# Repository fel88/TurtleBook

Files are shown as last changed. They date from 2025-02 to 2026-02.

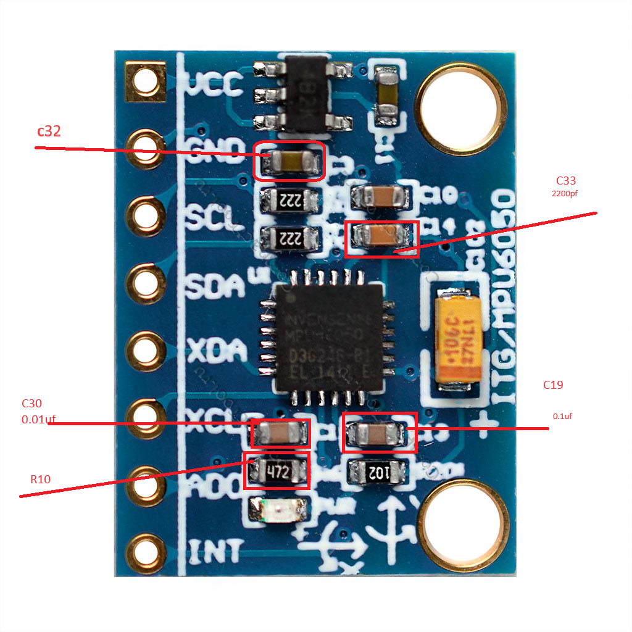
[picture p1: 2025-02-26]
pcbs/1369_1.png

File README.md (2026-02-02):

# TurtleBook

"_One book to read them all_"



Zero buttons, solar powered, fully autonomous and hermetic e-book reader.

For everyone who loves reading books and DIY projects.

Instructables:
https://www.instructables.com/Solar-Powered-Zero-Buttons-E-book-Reader/

WYSIWYG e-book. 

### Hardware
- Arduino MEGA2560 (https://aliexpress.ru/item/32967417746.html?sku_id=66568659813)
- Waveshare E-ink display 5,83” (648×480)  https://www.waveshare.com/5.83inch-e-paper.htm
- FRAM memory (FM24W256-GTR)
- WaveShare shield https://www.waveshare.com/product/displays/e-paper/e-paper-shield-b.htm
- Crystal oscillator KSE-7U16000MAB143ZA3
- OLED display (128x32 i2c)
- INA219 (https://aliexpress.ru/item/33047166203.html?sku_id=12000044300903777)
- SD-card slot
- MPU6050 (instead of buttons)
- Reed switch (turn on/off)
- Lithium-ion capacitors (LIC) 4x200F  (https://en.cda-cap.com/index.php/product/lib-series/) (https://item.szlcsc.com/3567431.html?lcsc_vid=QlRbX1wET1gIUAZeFVIKBFxWEwVWBVUAEVQKVVxUEwMxVlNSR1daUF1WT1RZXztW)
- Solar panel (something like this https://aliexpress.ru/item/1005008193807038.html?sku_id=12000044193770138)
- Buck-boost converter (https://aliexpress.ru/item/1005001525710076.html)
- NeoPixel (not necessarily)
- TL431 SOT89
- Ideal diodes (MAX40203), transistor (D882), resistors, etc
- Wires (https://aliexpress.ru/item/32793368381.html?sku_id=64310577090)

## How to assemble PCB 

### Panel driver PCB v5.0 (SRAM + Charger + Wifi integrated)
изображение

### Panel driver PCB v3.0 (no charger, no wifi)


You need next components to solder PCB board:
1. Arduino MEGA2560 
2. Waveshare shield
3. MPU6050
4. INA219
5. Crystal quartz
6. FRAM
   
## How to switch pages?

https://github.com/user-attachments/assets/5e0592eb-202e-4b6f-8b21-0b80249d7fce

## How many pages can I read?

If you have 3 LIC charged to 3.88V you can read about 880 pages (LICs will be discharged to 3.05V)

## How to convert books?
There are two options to convert (fb2/pdf/djvu/raw → cb): 
1. https://github.com/fel88/pdf2eink 
2. https://github.com/fel88/bookloader 

## Sample books
<a href="https://github.com/fel88/TurtleBook/blob/main/samples/nemo.zip">Twenty Thousand Leagues Under the Seas (Jules Verne)</a>

## Wifi (optional)

You can add Wemos D1 v3 module in order to use Wifi 

изображение

There are two ways of WiFi usage at the moment:
1. Wifi Access point: Web page (upload, download books). Use your phone/laptop to load books via browser
2. P2P sender/reciever. Direct book 2 book sharing

Components:
1. Wemos d1 v3 module
2. PNP transistor 2N3906
3. resistor 330

## Charger

A pass (series) regulator based on TL431 (adjust the output voltage level to ~3.95-3.98V)

Components:
1. resistor 330Ohm, 47kOhm
2. TL431
3. D882 (almost any NPN will do)
4. MAX40203
5. Pot 47kOhm

charger5

## Weight

Approx. 260g (with wemos d1)

## Gallery









## History

I am a big fan of reading books, so I've decided to make a small contribution to the world of e-readers .

I travel on the train a lot and I needed some reliable reader. That's why I decided to make DIY e-book reader.

Default e-readers have so many needless options. But all you need 99% of time is turn to next page.

E-ink paper don't consume power till you read it without switching. So Eink+solar power is very suitable combination of technologies.

This book doesn't contain any physical buttons. There is accelerometer inside the book and it can recognize your gestures. It can be used in discrete way (to switch page or to switch menu position in both directions), or it can be used in analog way (e.g. to set brightness of the NeoPixel led)

To turn on the book you just move special plastic key in special place. The internal reed switch will be activated and the book will turn on.

This book has some distinctions from the default e-reader and satisfy my needs better.

   - Solar powered (more autonomous)
   - No buttons. (you need to make some effort to switch the page like in real book)
   - Hybrid capacitors (LIC) instead of batteries
   - Sealed / hermetic ( you can use compound+expoxy resin to totally sealed the book and it'll become water proof)
   - More reliable plexiglass case . You can put cup of coffee on it or you can throw it in your backpack and not worry that it will break.
   - Nothing useless in the firmware
   - Open hardware and firmware
   - Eink for reading and small OLED for quick response menu operations

## Pre-history

It was inspired by my old project https://github.com/fel88/BIP and couple of github projects (https://hackaday.io/project/189366-supercaps-solar-panel-project/details) solar panel + supercap (https://github.com/aresta/Supercaps  it seems that it was moved to https://github.com/aresta/ESP32-C3_Supercaps )

Great quote from Aresta/Supercaps project:


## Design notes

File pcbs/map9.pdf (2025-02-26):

Sheet1
panel driver | | waveshare
R10 | 1K | R2
C19 | 100nF C11
C15 | 100nF C19
C1 | 100nF C8
C10 | 1uF | C6
C11 | 1uF | C7
C2 | 1uF | C9
C3 | 1uF | C10
C4 | 1uF | C12
C5 | 1uF | C13
C6 | 1uF | C14
C7 | 1uF | C15
C8 | 1uF | C16
C13 | 100nF C1
C18 | 100nF C2
D4 | | D1
R9 | 1K | R1
U3 | | U2
C17 | | C3
C16 | | C5
R8 | | R7
C14 | | C4
Q2 | | Q2
R6 | | R6
Q3 | | Q3
R4 | | R8
R3 | | R9
R5 | | R11
R7 | | R10
Q1 | | Q1
D3 | | D4
L1 | | L1

Sheet1
C9 | 4.7uF C18
C12 | 100nF C17
D2 | | D3
D1 | | D2
R2 | | R3
R1 | 10K | R5
panel driver | | mega
R11 | | R10
R12 | | R11
R13 | | R12
R14 | | R13
LED1 | | LED1
LED2 | | LED2
LED3 | | LED3
LED4 | | LED4
R15 | | R2
R16 | | R4
R17 | | R14
D5 | | D2
C21 | | C12
C25 | 0.1uF C1
C20 | 22uF | C11
C24 | 0.1uF C6
C26 | 0.1uF C7
C27 | 0.1uF C8
C28 | 0.1uF C9
C29 | 0.1uF C10
U4 | | U4
Y1 | 16Mhz Y2
C22 | 12pF | C13
C23 | 12pF | C14
R18 | 1M | R15

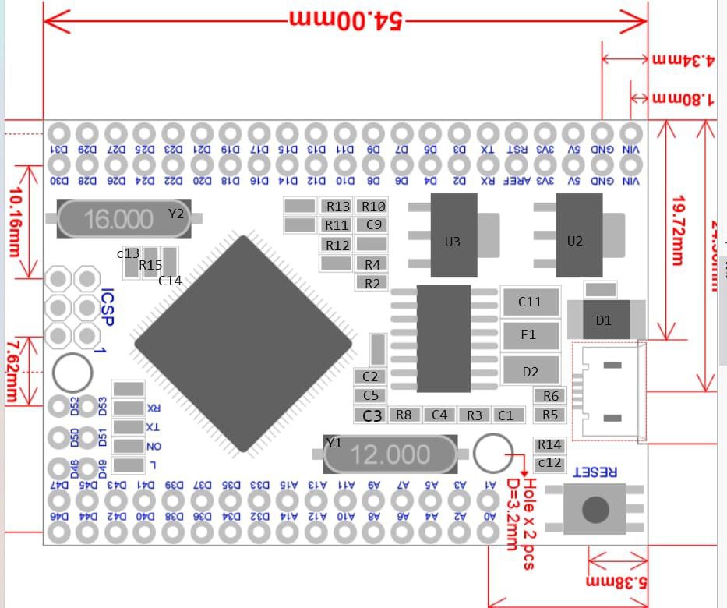
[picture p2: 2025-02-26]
pcbs/mega.jpg

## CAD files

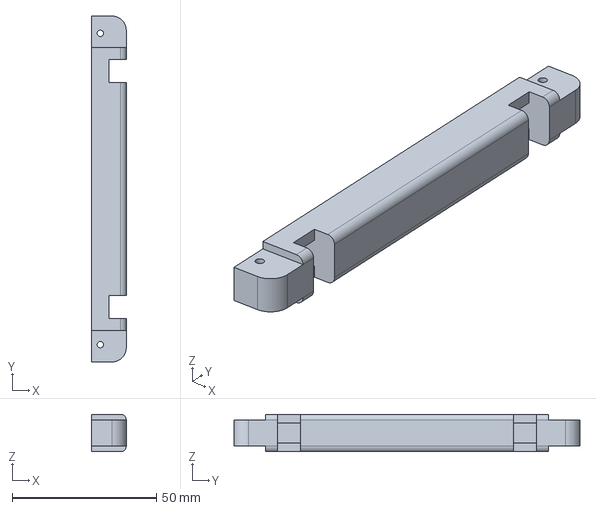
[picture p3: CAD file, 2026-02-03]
case/sider_stub_13mm.stp
12.0 x 120.0 x 13.0 mm

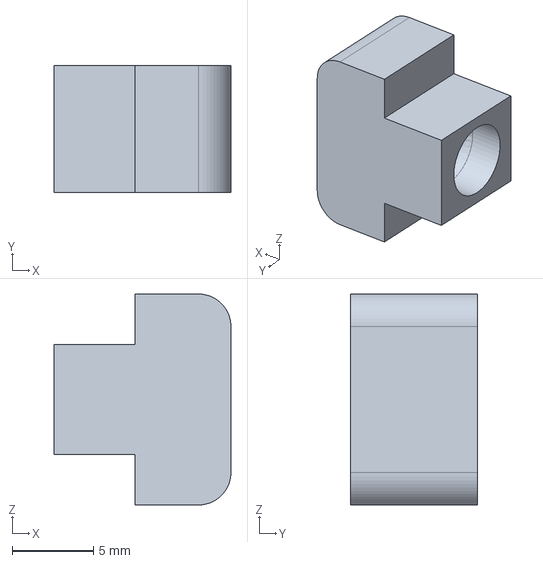
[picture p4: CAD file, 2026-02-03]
case/stub3_shrinked_13mm.stp
10.9 x 7.80 x 13.0 mm

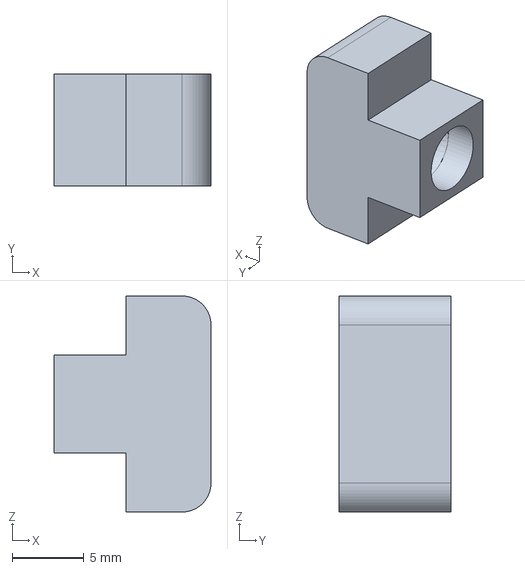
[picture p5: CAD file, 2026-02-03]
case/stub3_shrinked_3.stp
10.9 x 7.80 x 15.0 mm

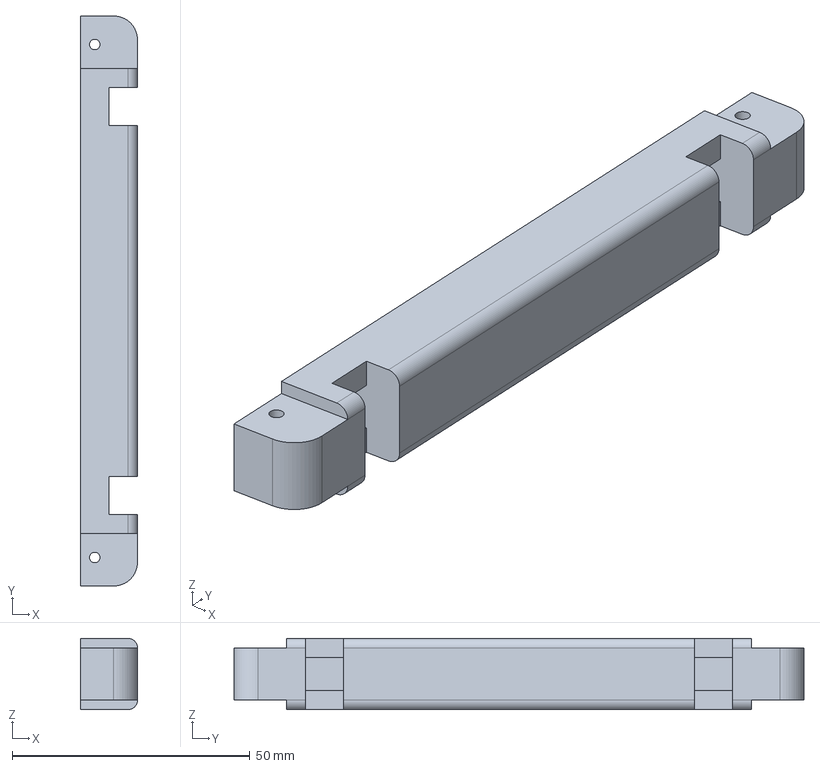
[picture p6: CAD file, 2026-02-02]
case/sider_stub2.stp
12.0 x 120.0 x 15.0 mm

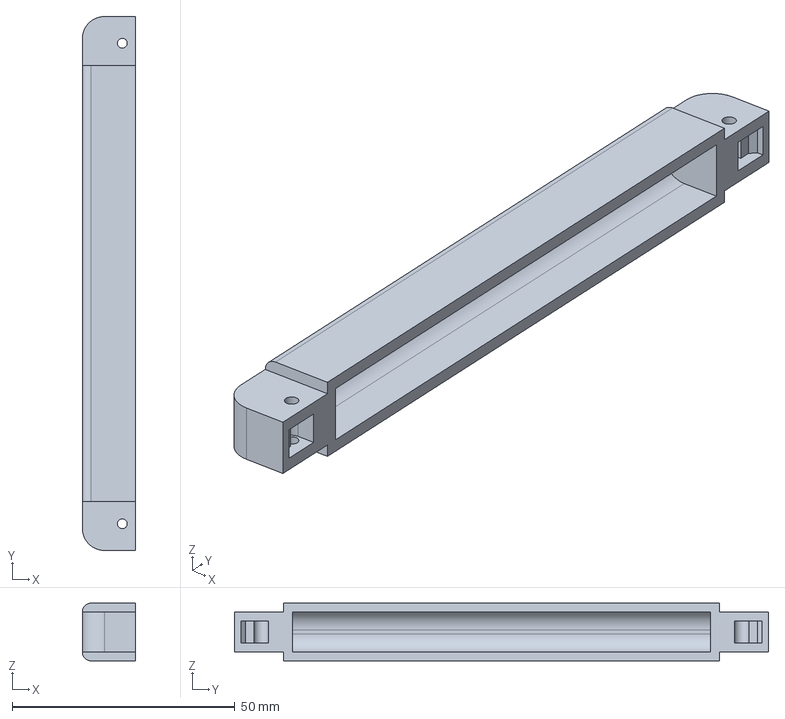
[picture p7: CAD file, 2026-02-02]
case/sider13mm_3.stp
12.0 x 120.0 x 13.0 mm

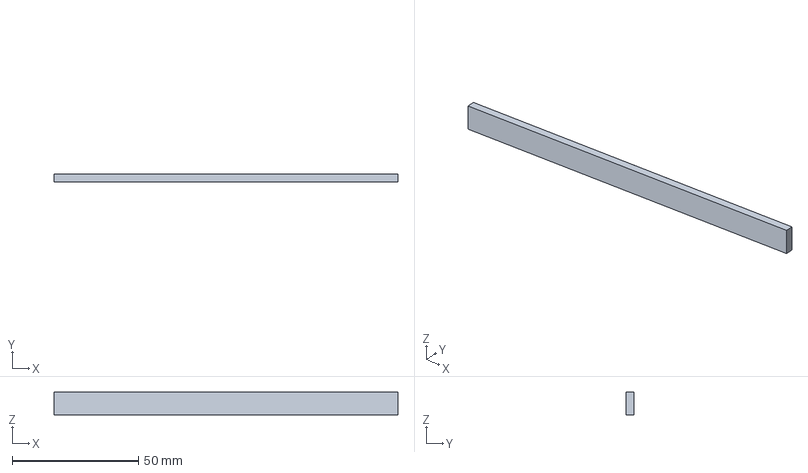
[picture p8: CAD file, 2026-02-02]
case/bare_spacer_9mm.stp
136.0 x 3.00 x 9.00 mm

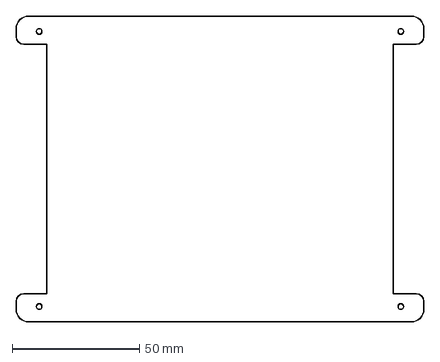
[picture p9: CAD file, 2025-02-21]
case/toptop.dxf
160.0 x 120.0 mm

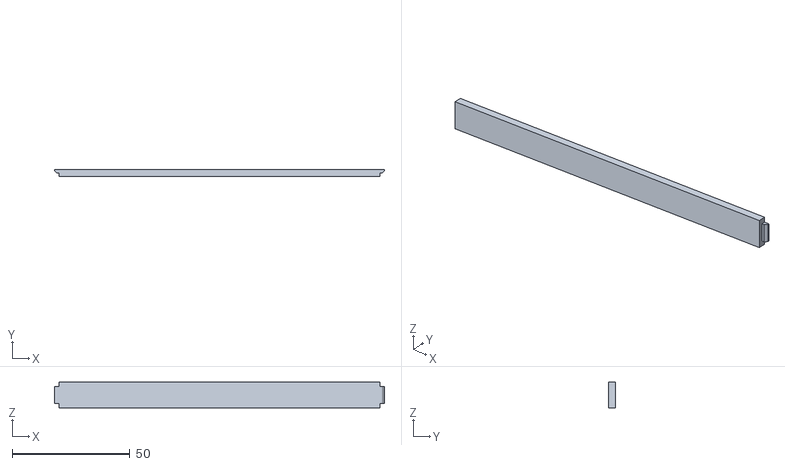
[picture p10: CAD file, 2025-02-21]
case/spacer_1mm.stl
140.0 x 3.00 x 11.0

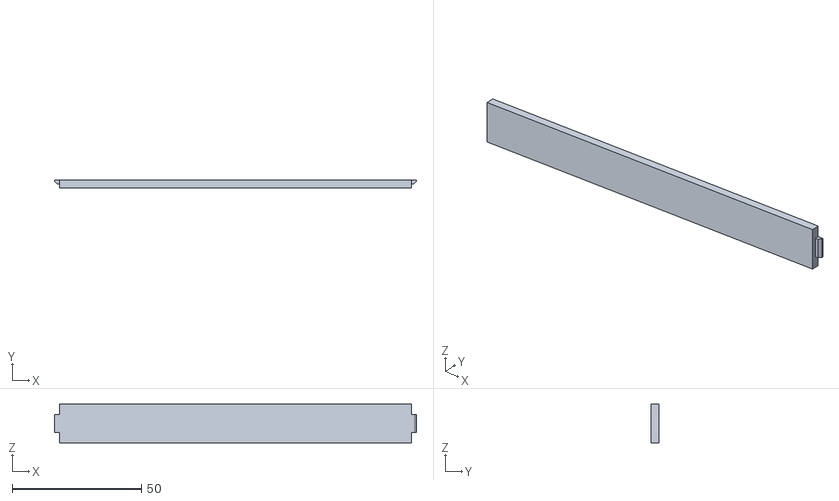
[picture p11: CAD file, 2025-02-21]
case/spacer_ext.obj
140.0 x 3.00 x 15.0

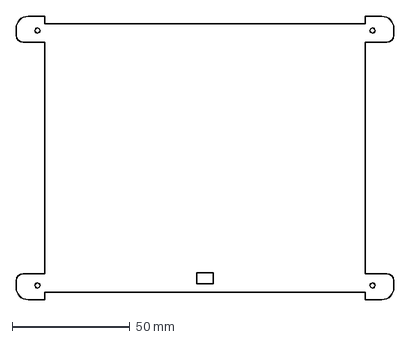
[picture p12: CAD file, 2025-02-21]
case/toptop3.dxf
160.0 x 120.0 mm

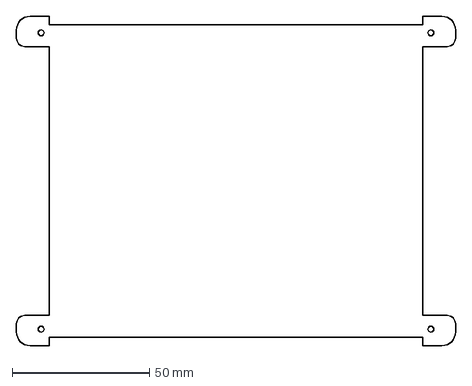
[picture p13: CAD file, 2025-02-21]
case/toptop2.dxf
160.0 x 120.0 mm

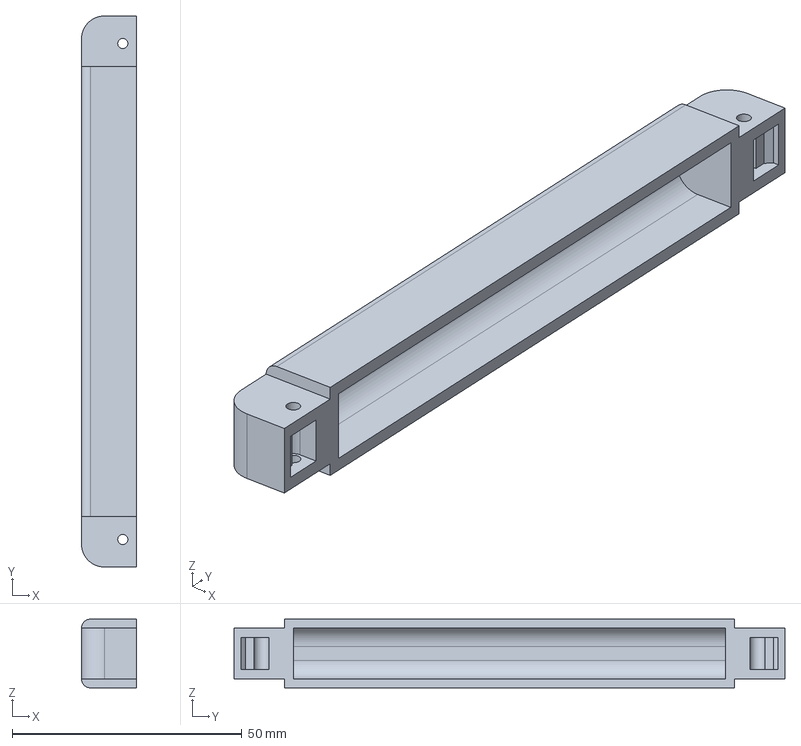
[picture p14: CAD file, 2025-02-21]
case/sider15mm_3.stp
12.0 x 120.0 x 15.0 mm

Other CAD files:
case/stub_shrinked_3.obj
case/spacer10x.stp
case/bare_spacer_ext.obj
case/sider_stub.obj
case/bare_spacer_11mm.stp
case/bare_spacer_15mm.stp
case/bare_spacer.obj
case/bare_spacer.stl
case/sider15mm_3.obj
case/spacer_1mm.obj

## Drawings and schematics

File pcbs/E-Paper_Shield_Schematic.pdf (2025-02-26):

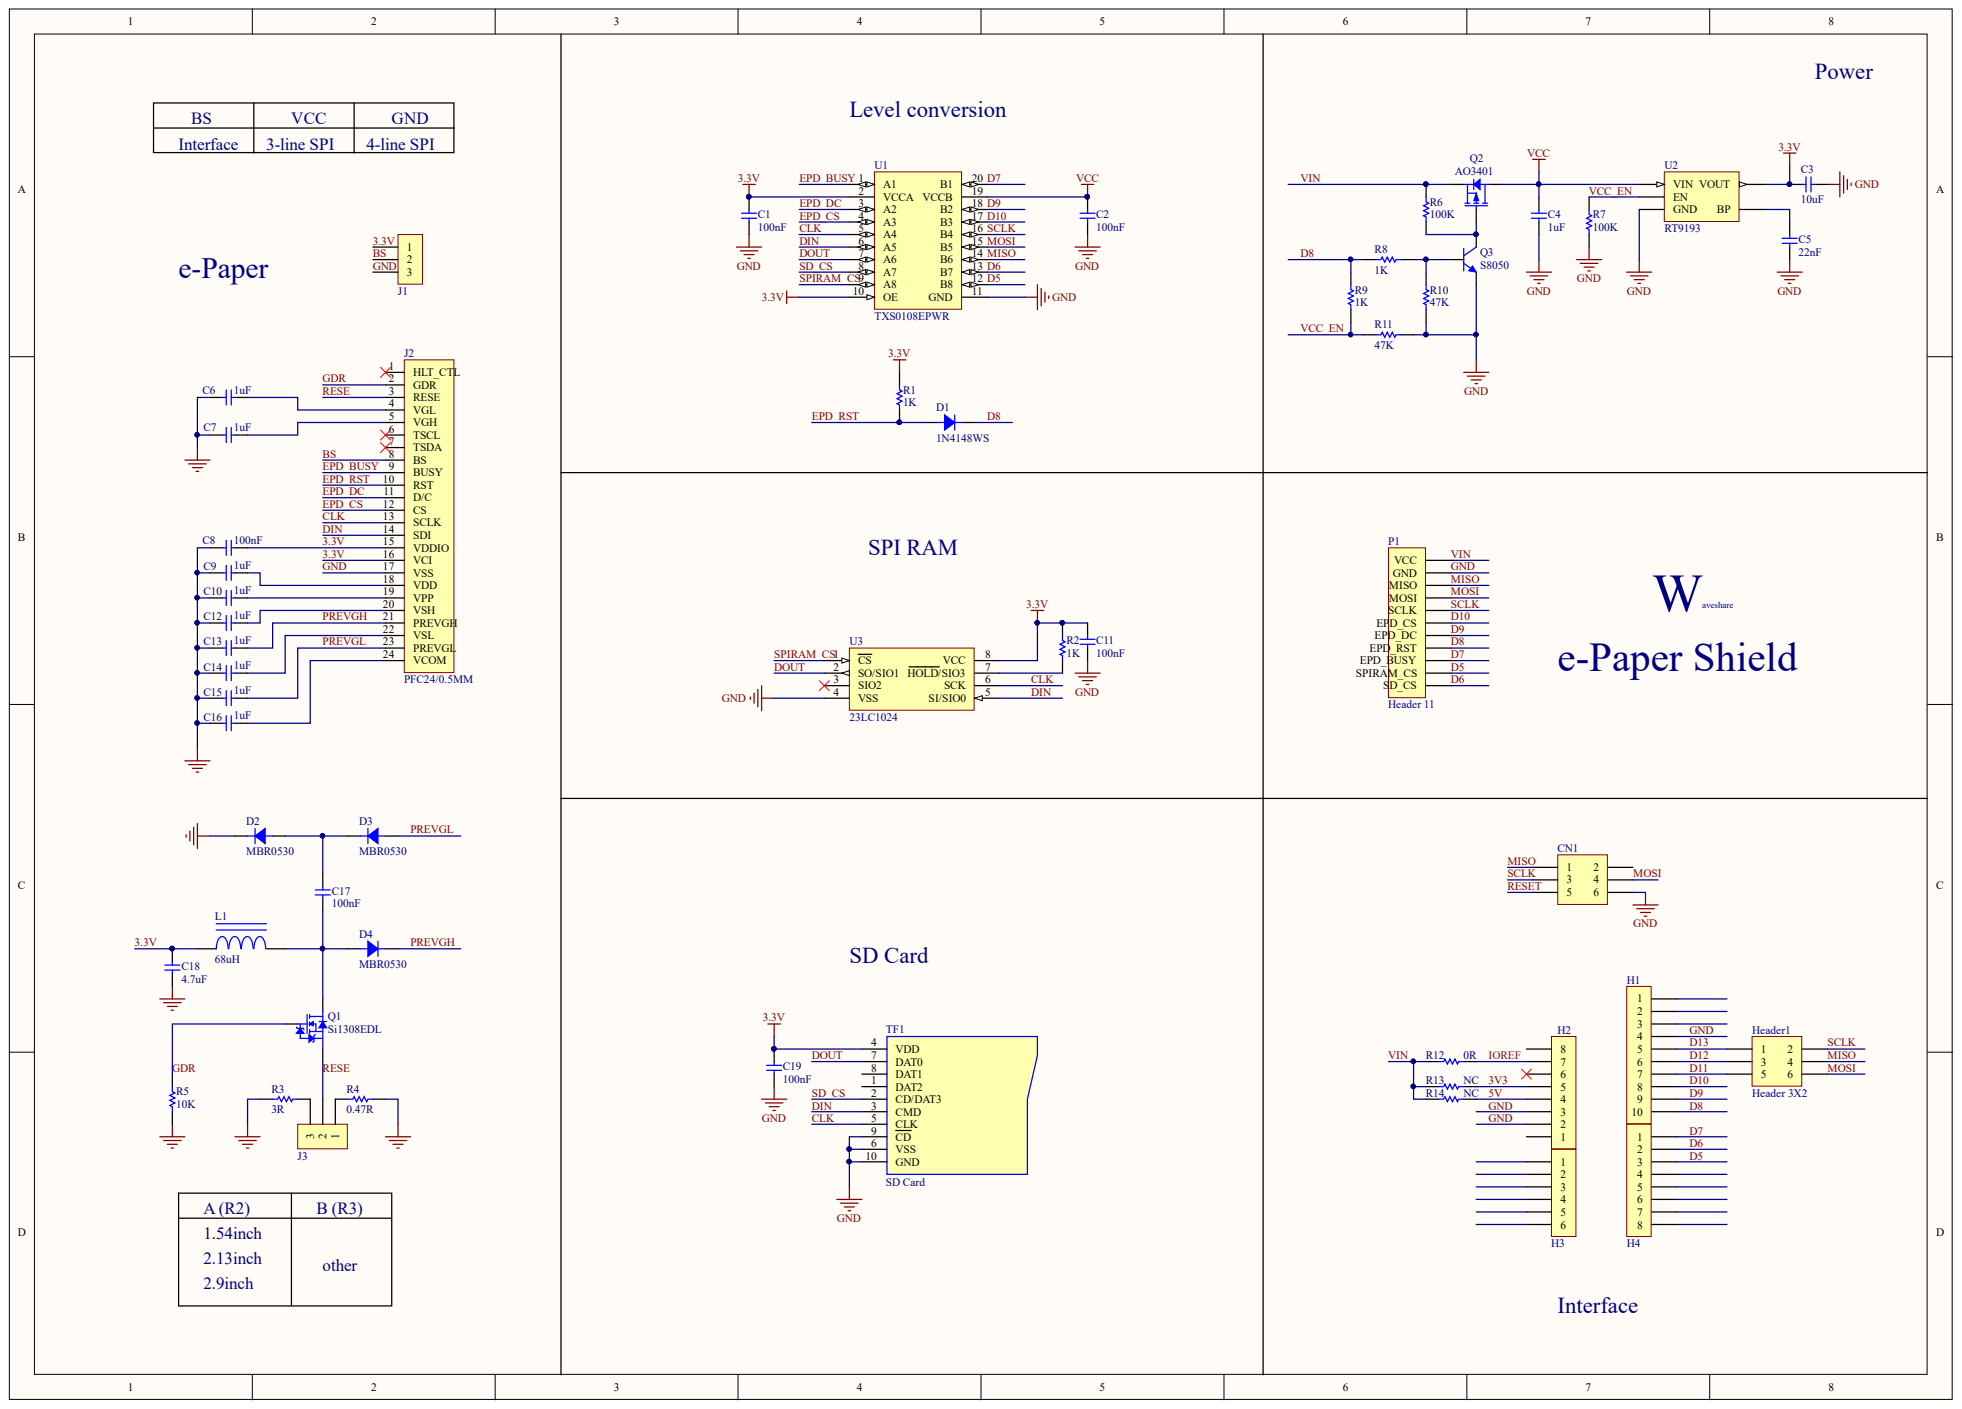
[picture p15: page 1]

BS | VCC | G N D
Int erfa c e | 3-l ine S P I | 4-l ine S P I

A (R2) | B (R3)
1.54inc h 2.13inc h 2.9inc h | othe r

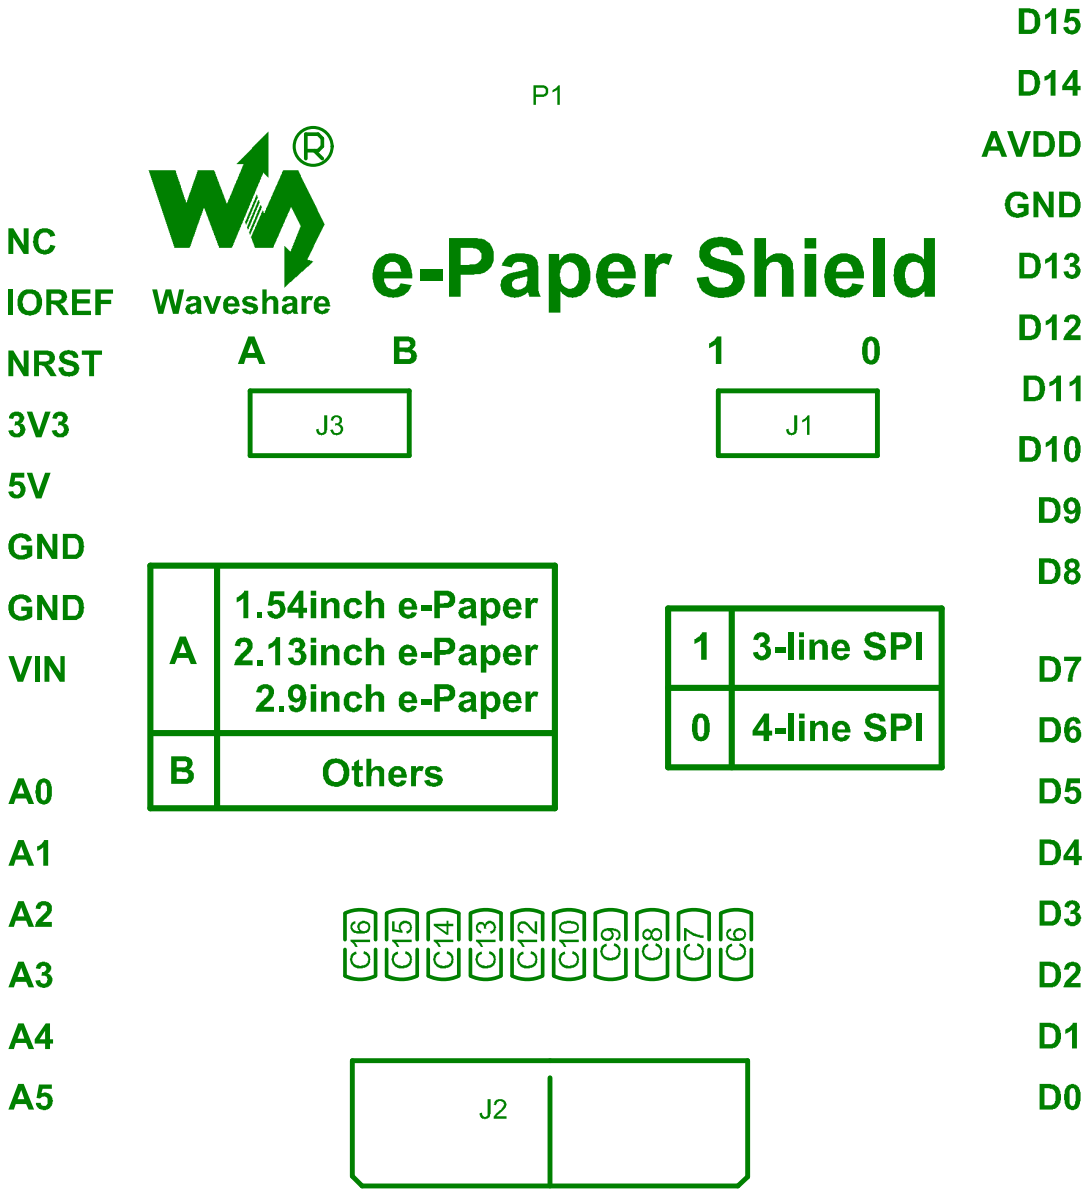
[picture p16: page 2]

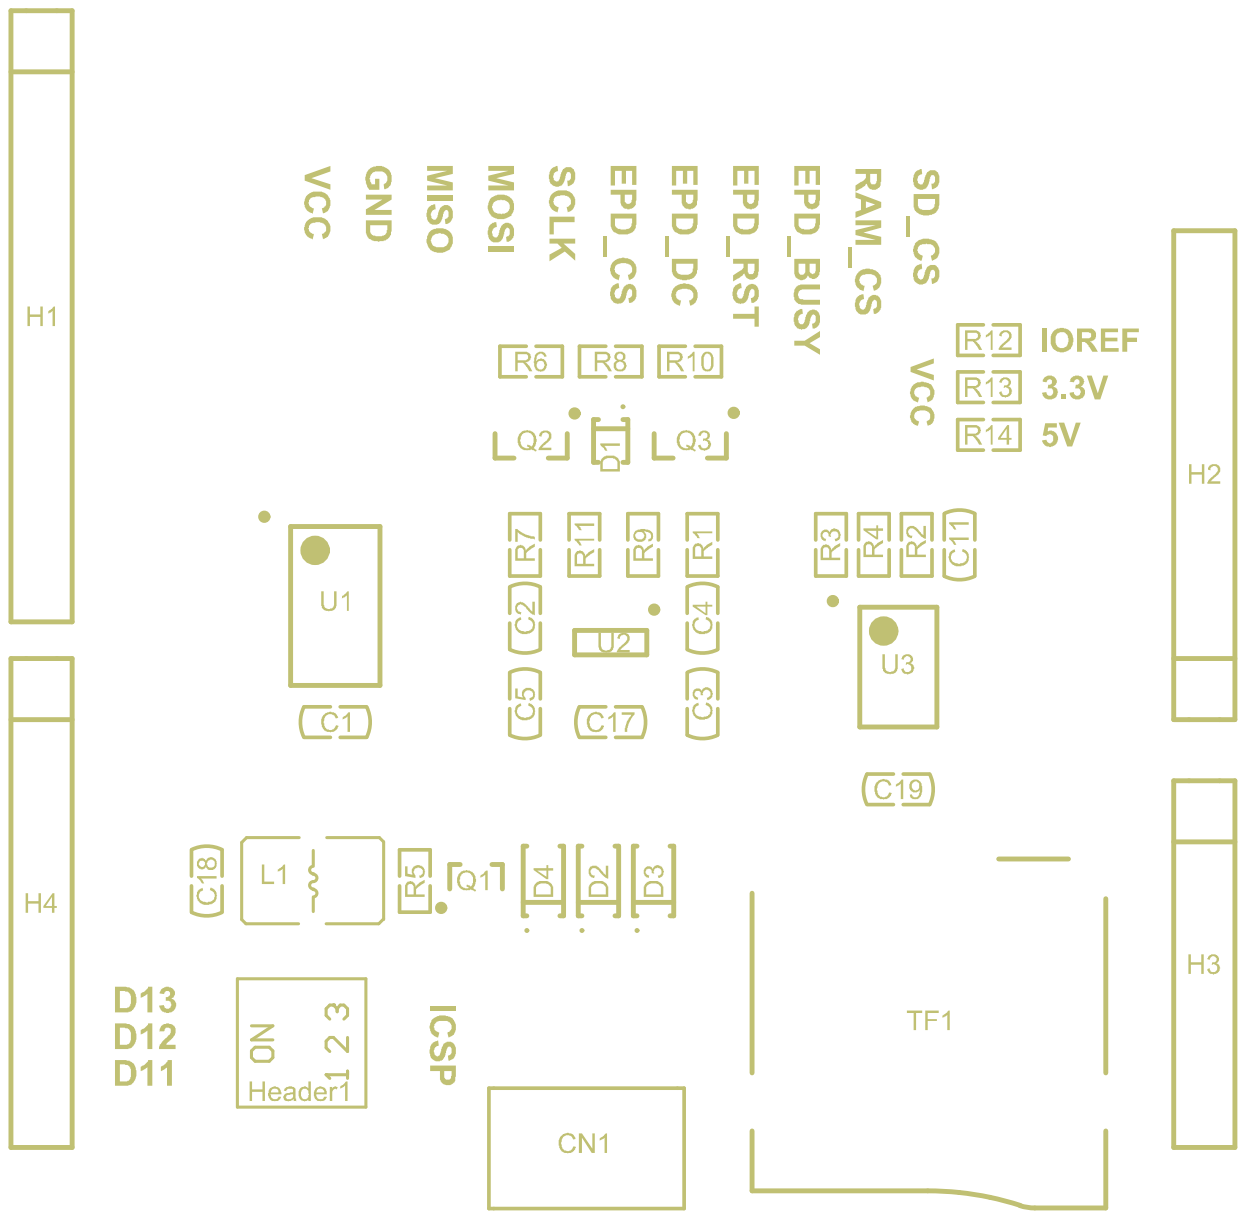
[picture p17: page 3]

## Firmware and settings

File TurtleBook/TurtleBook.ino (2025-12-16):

#include "EPD_My_sdfat.h"
#include "GUI_Paint.h"
#include "EPD_SDCard.h"
#include <avr/sleep.h>
#include <avr/power.h>
#include <avr/wdt.h>
#include <Adafruit_NeoPixel.h>
#include <EEPROM.h>

const byte reverse[256] PROGMEM = {
  0x00, 0x80, 0x40, 0xC0, 0x20, 0xA0, 0x60, 0xE0, 0x10, 0x90, 0x50, 0xD0, 0x30, 0xB0, 0x70, 0xF0,
  0x08, 0x88, 0x48, 0xC8, 0x28, 0xA8, 0x68, 0xE8, 0x18, 0x98, 0x58, 0xD8, 0x38, 0xB8, 0x78, 0xF8,
  0x04, 0x84, 0x44, 0xC4, 0x24, 0xA4, 0x64, 0xE4, 0x14, 0x94, 0x54, 0xD4, 0x34, 0xB4, 0x74, 0xF4,
  0x0C, 0x8C, 0x4C, 0xCC, 0x2C, 0xAC, 0x6C, 0xEC, 0x1C, 0x9C, 0x5C, 0xDC, 0x3C, 0xBC, 0x7C, 0xFC,
  0x02, 0x82, 0x42, 0xC2, 0x22, 0xA2, 0x62, 0xE2, 0x12, 0x92, 0x52, 0xD2, 0x32, 0xB2, 0x72, 0xF2,
  0x0A, 0x8A, 0x4A, 0xCA, 0x2A, 0xAA, 0x6A, 0xEA, 0x1A, 0x9A, 0x5A, 0xDA, 0x3A, 0xBA, 0x7A, 0xFA,
  0x06, 0x86, 0x46, 0xC6, 0x26, 0xA6, 0x66, 0xE6, 0x16, 0x96, 0x56, 0xD6, 0x36, 0xB6, 0x76, 0xF6,
  0x0E, 0x8E, 0x4E, 0xCE, 0x2E, 0xAE, 0x6E, 0xEE, 0x1E, 0x9E, 0x5E, 0xDE, 0x3E, 0xBE, 0x7E, 0xFE,
  0x01, 0x81, 0x41, 0xC1, 0x21, 0xA1, 0x61, 0xE1, 0x11, 0x91, 0x51, 0xD1, 0x31, 0xB1, 0x71, 0xF1,
  0x09, 0x89, 0x49, 0xC9, 0x29, 0xA9, 0x69, 0xE9, 0x19, 0x99, 0x59, 0xD9, 0x39, 0xB9, 0x79, 0xF9,
  0x05, 0x85, 0x45, 0xC5, 0x25, 0xA5, 0x65, 0xE5, 0x15, 0x95, 0x55, 0xD5, 0x35, 0xB5, 0x75, 0xF5,
  0x0D, 0x8D, 0x4D, 0xCD, 0x2D, 0xAD, 0x6D, 0xED, 0x1D, 0x9D, 0x5D, 0xDD, 0x3D, 0xBD, 0x7D, 0xFD,
  0x03, 0x83, 0x43, 0xC3, 0x23, 0xA3, 0x63, 0xE3, 0x13, 0x93, 0x53, 0xD3, 0x33, 0xB3, 0x73, 0xF3,
  0x0B, 0x8B, 0x4B, 0xCB, 0x2B, 0xAB, 0x6B, 0xEB, 0x1B, 0x9B, 0x5B, 0xDB, 0x3B, 0xBB, 0x7B, 0xFB,
  0x07, 0x87, 0x47, 0xC7, 0x27, 0xA7, 0x67, 0xE7, 0x17, 0x97, 0x57, 0xD7, 0x37, 0xB7, 0x77, 0xF7,
  0x0F, 0x8F, 0x4F, 0xCF, 0x2F, 0xAF, 0x6F, 0xEF, 0x1F, 0x9F, 0x5F, 0xDF, 0x3F, 0xBF, 0x7F, 0xFF
};
char temp128[128];
const int triggerDelay = 300;
uint8_t triggerCounter = 0;

uint8_t OledContrast = 0x5;

const float VoltageShutDownTreshold = 3.05;

uint8_t TriggerCheckDivisor = 25;

#include <Wire.h>
#define disk 0x50  //адрес чипа FM24C

#define WEMOS_PMOS_PIN 11

// Which pin on the Arduino is connected to the NeoPixels?
#define NEO_PIN 7  // todo: change to 14/15
// When setting up the NeoPixel library, we tell it how many pixels,
// and which pin to use to send signals. Note that for older NeoPixel
// strips you might need to change the third parameter -- see the
// strandtest example for more information on possible values.
Adafruit_NeoPixel pixels(1, NEO_PIN, NEO_GRB + NEO_KHZ800);

#include "Adafruit_EEPROM_I2C.h"
#include "Adafruit_FRAM_I2C.h"

Adafruit_EEPROM_I2C i2ceeprom;

bool applyRevert = false;
bool screensRevert = false;

#define EEPROM_ADDR 0x50  // the default address!

int FramReadInt(int addr) {
  uint8_t buffer[2];  // floats are 4 bytes!
  int ret = 0;
  i2ceeprom.read(addr, buffer, 2);
  memcpy((void*)&ret, buffer, 2);
  return ret;
}

long FramReadLong(int addr) {
  uint8_t buffer[4];  // floats are 4 bytes!
  long ret = 0;
  i2ceeprom.read(addr, buffer, 4);
  memcpy((void*)&ret, buffer, 4);
  return ret;
}
void FramWriteInt(int addr, int val) {
  uint8_t buffer[2];  // floats are 4 bytes!
  memcpy(buffer, (void*)&val, 2);
  i2ceeprom.write(addr, buffer, 2);
}
void FramWriteLong(int addr, long val) {
  uint8_t buffer[4];  // floats are 4 bytes!
  memcpy(buffer, (void*)&val, 4);
  i2ceeprom.write(addr, buffer, 4);
}
//#define USE_DEBUG 0

int perSessionPages = 0;

//FRAM addresses
const int TotalPagesFramAddress = 0;
const int CounterPagesFramAddress = 4;
const int BookmarkFlagsRegisterFramAddress = 8;
const int BookmarkPageFramAddress = 10;
const int BookmarkFilenameFramAddress = 12;

///////
int bookMenuStatisticIdx = 0;  //0-voltage,1-mV/page,2-pages,3-startup voltage

void FM24C_write(unsigned int startAddress, void* data, unsigned int len) {  // адрес, указатель на первый байт, длина в байтах
  Wire.beginTransmission(disk);
  Wire.write((byte*)&startAddress, 2);
  Wire.write((byte*)data, len);
  Wire.endTransmission(true);
  delay(1);
}

int FM24C_read(unsigned int startAddress, void* data, unsigned int len) {  // возвращаем кол-во считанных байт
  byte rdata;
  byte* p;
  Wire.beginTransmission(disk);
  Wire.write((byte*)&startAddress, 2);
  Wire.endTransmission();
  //Wire.beginTransmission(disk);
  Wire.requestFrom(disk, len);
  for (rdata = 0, p = (byte*)data; Wire.available() && rdata < len; rdata++, p++) {
    *p = Wire.read();
  }
  return (rdata);
}

void WriteString(int addr, String str) {


  // Serial.print("strlen:");
  int len = str.length();
  // Serial.println(len);
  FM24C_write(addr, &len, sizeof(len));  // адрес 10

  const char* ss = str.c_str();
  for (int i = 0; i < len / 16; i++) {
    FM24C_write(addr + sizeof(len) + i * 16, ss + i * 16, 16 + 1);  // записываем по адресу 1500*/
  }
  if (len % 16 > 0) {
    FM24C_write(addr + sizeof(len) + (len / 16) * 16, ss + (len / 16) * 16, len % 16 + 1);  // записываем по адресу 1500*/
  }
}

String ReadString(int addr) {
  int len;
  FM24C_read(addr, &len, sizeof(len));  // из тех же адресов, что записывали!
  //Serial.println(b);

  char hhh[256];
  for (int i = 0; i < len / 16; i++) {
    int br = FM24C_read(addr + sizeof(len) + i * 16, hhh + i * 16, 16 + 1);  // считываем из того же адреса
    //Serial.print("bytes readed:");
    // Serial.println(br);
  }
  if (len % 16 > 0) {
    int br = FM24C_read(addr + sizeof(len) + (len / 16) * 16, hhh + (len / 16) * 16, len % 16 + 1);  // считываем из того же адреса
    //Serial.print("bytes readed:");
    //Serial.println(br);
  }
  return String(hhh);
}
//Analog port 4 (A4) = SDA (serial data)
//Analog port 5 (A5) = SCL (serial clock)


#define ACCEL_CONFIG 0x1C
#define MOT_THR 0x1F  // Motion detection threshold bits [7:0]
#define MOT_DUR 0x20  // Duration counter threshold for motion interrupt generation, 1 kHz rate, LSB = 1 ms
#define FIFO_EN 0x23
#define I2C_MST_CTRL 0x24
#define I2C_SLV0_ADDR 0x37
#define SIGNAL_PATH_RESET 0x68
#define MOT_DETECT_CTRL 0x69
#define INT_ENABLE 0x38
#define USER_CTRL 0x6A   // Bit 7 enable DMP, bit 3 reset DMP
#define PWR_MGMT_1 0x6B  // Device defaults to the SLEEP mode
#define PWR_MGMT_2 0x6C
#define WHO_AM_I_MPU6050 0x75  // Should return 0x68
#define INT_STATUS 0x3A



//when nothing connected to AD0 than address is 0x68
#define ADO 0
#if ADO
#define MPU6050_ADDRESS 0x69  // Device address when ADO = 1
#else
#define MPU6050_ADDRESS 0x68  // Device address when ADO = 0
#endif
//#include "EPD_5in83.h"
//#include "utility/EPD_5in83.h"

bool wifiMode = false;
#include <Arduino.h>
#include <U8g2lib.h>

//#ifdef U8X8_HAVE_HW_SPI
//#include <SPI.h>
//#endif
//#ifdef U8X8_HAVE_HW_I2C
#include <Wire.h>
//#endif

#include <INA219_WE.h>
#define I2C_ADDRESS 0x40
/*U8G2_SSD1306_128X64_NONAME_F_HW_I2C*/
U8G2_SSD1306_128X32_UNIVISION_F_HW_I2C u8g2(U8G2_R0, /* clock=*/SCL, /* data=*/SDA, /* reset=*/U8X8_PIN_NONE);  // All Boards without Reset of the Display
INA219_WE ina219 = INA219_WE(I2C_ADDRESS);

const int max_characters = 80;
char f_name[max_characters];

//const int buttonPin3 = 19;  // the number of the pushbutton pin
const int buttonPin = 19;  // 19 for old panel driver2

byte format1 = 0;  //format of opened cb book
long bookInfoSectionOffset;
long pagesArraySectionOffset;
long pagesTableSectionOffset;

const int wemosPin = 30;
const int wemosRstPin = 31;
//const int buttonPin2 = 35;     // the number of the pushbutton pin
File file;

bool outdoorMode = false;

String root_dir = "/";
String cut_file_path = "/";  //path to cut file
String cut_file_name = "";   //file name of cut file

sFONT* font = &Font12;

int fontHeight = 12;
//int cols=54;//35 for font24; 54 for font16;85 for font12
//int rows=22;//17 for font24; 27 for font16; 29 for font12(gap=3)
int cols = 80;  //35 for font24; 54 for font16;85 for font12
int rows = 25;  //17 for font24; 27 for font16; 29 for font12(gap=3)
int page = 1;
int pages = 778;
//int gap=2;
int gap = 3;
//int fontWidth=11;//11 for font16, 17 for font24, 7 for font12
int fontWidth = 7;  //11 for font16, 17 for font24, 7 for font12

int bookMenuPos = 0;      //0- back to book,1-goto page menu, 2- close book
int bootMenuPos = 0;      //0 - load bookmarks list, 1- load files list, 2- settings, 3- wifi
int settingsMenuPos = 0;  //
int ledMenuIdx = 0;       //
int chaptersMenuIdx = 0;  //
int statisticsMenuIdx = 0;
int bookmarkMenuPos = 0;
int totalBookmarks = 0;
int totalFastBookmarks = 0;
int fastbookmarkLevels = 0;  // level of binary tree
int maxPriority = 0;
int minPriority = 0;
int minPriorityIdx = 0;

UWORD Image_Width_Byte;
UWORD Bmp_Width_Byte;
int width;
int bookWidth;
int height;
int bookHeight;
unsigned long tocRawSize;
int tocItems;


extern SdFat sd;

#define MFILE_WRITE (O_RDWR | O_CREAT | O_AT_END)
#define MFILE_READ (O_RDONLY)

const size_t LINE_DIM = 550;
char line[LINE_DIM];

int cbPage = 0;

String currentBook = "";
int currentBookIdx = 0;

enum class menuModeEnum {
  files,
  textBook,      //1-text book inside,
  CB,            //2- CB book inside
  bookMenu,      //3-book menu(goto page,back to files),
  gotoPageMenu,  //4-goto page menu,
  bootMenu,      // 5-boot menu,
  bookmarks,     // 6 - bookmarks list
  bmp,           // 7- bmp image,
  settings,      //8- settings list
  statistics,    //9- statistics menu
  led
} menuMode;


int gotoPage = 0;
int gotoPageMenu = 0;
//bool hasBookmark=false;

void saveBookmark(int page) {
  //Serial.println("saveb");
  char buffer[380];
  maxPriority++;
  sprintf(buffer, "%s;%6d;%6d", (root_dir + currentBook).c_str(), page, maxPriority);
  //Serial.print(buffer);
  int p = getBookmark();
  //Serial.println(p);

  if (p == -1) {
    File fileB = sd.open("bookmarks.txt", MFILE_WRITE);
    fileB.println(buffer);
    //Serial.print("puts line");
    fileB.close();
    //   hasBookmark=true;
  } else {
    replaceBookmark(page);
  }
}

int replaceBookmark(int page) {
  //Serial.println("replaceBookmark");
  char buffer[320];
  sprintf(buffer, "%s", (root_dir + currentBook).c_str());
  //Serial.println(buffer);
  File fileB = sd.open("bookmarks.txt", MFILE_READ);
  size_t n;
  // if the file opened okay, write to it:
  if (fileB) {
    long long pos = -1;
    char rep[20];
    while ((n = fileB.fgets(line, sizeof(line))) > 0) {
      char* pch;
      pch = strtok(line, ";");

      //  Serial. printf ("%s\n",pch);
      //   pch = strtok(NULL, ";");
      if (!strcmp(pch, buffer)) {

        maxPriority++;
        auto len = sprintf(rep, "%6d;%6d", page, maxPriority);
        rep[len] = '\0';
        //Serial.print("sprintf len:");
        //Serial.println(len);

        pos = fileB.position() - n + strlen(pch);
        //Serial.print("pos:");
        /*Serial.println((int)(pos));
Serial.print("n:");
Serial.println(n);
Serial.print("rep:");
Serial.println(rep);
Serial.print("strlen(rep):");
Serial.println(strlen(rep));
Serial.print("strlen(pch):");
Serial.println(strlen(pch));*/
        //fileB.seek(pos);  //6+newline
        //fileB.write(rep);


        break;
      }
    }

    fileB.close();
    File fileB = sd.open("bookmarks.txt", O_WRONLY);
    fileB.seek(pos);  //6+newline
    fileB.write(rep, 13);
    fileB.close();
  } else
    // Serial.println("arduino_bookmarks.txt not found");
    return -1;
}

//UDOUBLE SDCard_Read32(File f);
long GetSectionOffset(File& f, byte searchType) {
  auto temp = f.position();
  f.seek(4);
  long pos = 4;
  long ret = -1;
  auto flen = f.size();
  while (pos < flen) {
    auto len = SDCard_Read32(f);
    auto type = file.read();

    if (type == searchType) {
      ret = pos;
      break;
    }


    pos += len;
    f.seek(pos);
  }
  f.seek(temp);
  return ret;
}

int printFile(const char* path) {
  //Serial.print("print file: ");
  // Serial.println(path);
  char buffer[333];

  File fileB = sd.open(path, MFILE_READ);
  int n;
  //Serial.print(buffer);
  if (fileB) {
    while ((n = fileB.fgets(buffer, sizeof(line))) > 0) {
      // Serial.println(buffer);
    }
    fileB.close();
  } else {
    // Serial.println("file not found");
  }
  return -1;
}
int getBookmark() {
  // Serial.println("getb");

  char buffer[280];
  sprintf(buffer, "%s", (root_dir + currentBook).c_str());
  File fileB = sd.open("bookmarks.txt", MFILE_READ);
  size_t n;
  //Serial.print(buffer);
  if (fileB) {
    while ((n = fileB.fgets(line, sizeof(line))) > 0) {
      /*char* pch;
      pch = strtok(line, ";");
      int cntr = 0;*/

      char* pch;
      char* pch2;
      pch = strtok(line, ";");
      pch2 = strtok(NULL, ";");
      int page = atoi(pch2);
      //Serial.println(pch);
      if (!strcmp(pch, buffer)) {
        // Serial.print("found");
        pch = strtok(NULL, ";");
        // Serial.print(pch);


        //Serial.print(page);
        return page;
      }
      //cntr++;
    }
    fileB.close();
  } else {
    //Serial.println("bookmarks.txt not found");
  }
  return -1;
}

void SDCard_ReadCB(const char* Name) {
  //Serial.println("cp1");

#ifdef USE_DEBUG
  Serial.println("SDCard_ReadCB");
  Serial.println(Name);
#endif
  //file = sd.open(Name,O_READ );

  //Serial.println(file.size());
  if (!file.open(Name, O_RDONLY)) {
    //  Serial.println("not found");
    DEBUG("not find : ");
    DEBUG(Name);
    DEBUG("\n");
    return;
  } else {
    DEBUG("open bmp file : ");
    DEBUG(Name);
    DEBUG("\n");
  }

  //if (!SDCard_ReadBmpHeader(bmpFile)) {
  //  DEBUG("read bmp file error\n");
  //  return;
  // }
  UWORD File_Type;
  File_Type = SDCard_Read16(file);  //0000h 2byte: file type

  // Serial.println(File_Type);

  if (File_Type != 0x4243) {
    // magic bytes missing
    return false;
  }

  format1 = file.read();
  auto format2 = file.read();

  //reset toc
  tocItems = 0;
  tocRawSize = 0;

  if (format1 == 0x2) {
    //sections format
    long pos = 4;
    bookInfoSectionOffset = GetSectionOffset(file, 0x10) + 5;
    pagesArraySectionOffset = GetSectionOffset(file, 0xC0);
    pagesTableSectionOffset = GetSectionOffset(file, 0xB0) + 9;
    file.seek(bookInfoSectionOffset);
  }
  pages = SDCard_Read32(file);
  //  Serial.print("pages: ");
  // Serial.println(pages);

  width = SDCard_Read16(file);
  height = SDCard_Read16(file);

  if (format2 == 0x1) {  //simple toc section
    tocItems = SDCard_Read32(file);
    tocRawSize = SDCard_Read32(file);
    file.seek(12ul + tocRawSize);
  }

  bookWidth = width;
  bookHeight = height;

  UWORD X, Y;
  Image_Width_Byte = (width % 8 == 0) ? (width / 8) : (width / 8 + 1);
  Bmp_Width_Byte = (Image_Width_Byte % 4 == 0) ? Image_Width_Byte : ((Image_Width_Byte / 4 + 1) * 4);
  //unsigned long offset=12ul+5ul*76ul*448ul;
  //file.seek(offset);

  WriteString(BookmarkFilenameFramAddress, String(Name));
  //String str( Name);
  //i2ceeprom.writeObject(BookmarkFilenameFramAddress, String(Name));

  int a = 0;  //0 page
  a = FramReadInt(BookmarkPageFramAddress);
  //FM24C_write(BookmarkPageFramAddress, &a, sizeof(a));

  a = 1;  //flag setted to 1. indicate that book appear
  //  FM24C_write(BookmarkFlagsRegisterFramAddress, &a, sizeof(a));
  FramWriteInt(BookmarkFlagsRegisterFramAddress, a);
}

void resetCB() {
  file.seek(12);
  cbPage = 0;
}

//const unsigned long bytesPerPageCB = 76ul * 448ul;
void skipPagesCB(int cnt) {

  int stride = 4 * (int)ceil(bookWidth / 8 / 4.0f);  //aligned 4

  unsigned long bytesPerPageCB = (unsigned long)stride * (unsigned long)bookHeight;
  //unsigned long bytesPerPageCB = 76ul * 448ul;
  unsigned long offset = (12ul + tocRawSize) + ((unsigned long)cnt) * bytesPerPageCB;

  file.seek(offset);
  cbPage += cnt;
}

extern UBYTE _readBuff[801];

long GetPageOffset(File& file, int page) {
  file.seek(pagesTableSectionOffset + page * 4);
  auto pos = SDCard_Read32(file);
  return pagesArraySectionOffset + pos;
}

void fastNextPageCB() {

  if (format1 == 0x2) {
    //seek to page first to all

    //get page offset
    auto pOffset = GetPageOffset(file, cbPage);
    file.seek(pOffset);
    auto pageType = file.read();
  }
  UWORD X, Y;
  cbPage++;
  UBYTE Data_Black, Data;
  EPD_5IN83_V2_SendCommand(0x10);
  UBYTE ReadBuff[1] = { 0 };


  int Width = (EPD_5IN83_V2_WIDTH % 8 == 0) ? (EPD_5IN83_V2_WIDTH / 8) : (EPD_5IN83_V2_WIDTH / 8 + 1);
  int Height = EPD_5IN83_V2_HEIGHT;

  //EPD_5IN83_V2_SendCommand(0x10);
  for (int i = 0; i < Height; i++) {
    for (int j = 0; j < Width; j++) {
      EPD_5IN83_V2_SendData(0x00);
    }
  }
  EPD_5IN83_V2_SendCommand(0x13);
  if (screensRevert) {
    for (Y = 0; Y < height; Y++) {  //Total display column
      file.read(_readBuff, Bmp_Width_Byte);
      for (X = 0; X < Bmp_Width_Byte; X++) {  //Show a line in the line
        //file.read(ReadBuff, 1);


        //ReadBuff[0]=reverse(ReadBuff[0]);
        if (X >= Image_Width_Byte)
          break;

        // if (Paint_Image.Image_Color == IMAGE_COLOR_POSITIVE) {

        //Data_Black = ~reverse[_readBuff[Bmp_Width_Byte - X - 1]];
        Data_Black = _readBuff[Bmp_Width_Byte - X - 1];
        // } else {
        //   Data_Black = ~_readBuff[X];
        //  }
        EPD_5IN83_V2_SendData(Data_Black);
      }
      //bmpFile.read(ReadBuff, 1);
    }
  } else {
    auto limit = min(Bmp_Width_Byte, Image_Width_Byte);
    for (Y = 0; Y < height; Y++) {  //Total display column
      file.read(_readBuff, Bmp_Width_Byte);

      for (X = 0; X < limit; X++) {  //Show a line in the line
        //file.read(ReadBuff, 1);


        //ReadBuff[0]=reverse(ReadBuff[0]);
        //if (X >= Image_Width_Byte)
        //break;

        // if (Paint_Image.Image_Color == IMAGE_COLOR_POSITIVE) {

        //Data_Black = _readBuff[X];
        // } else {
        //   Data_Black = ~_readBuff[X];
        //  }
        EPD_5IN83_V2_SendData(_readBuff[X]);
      }
      //bmpFile.read(ReadBuff, 1);
    }
  }
  EPD_5IN83_V2_Power(false);


  int temp = cbPage - 2;
  //FM24C_write(BookmarkPageFramAddress, &temp, sizeof(temp));
  FramWriteInt(BookmarkPageFramAddress, temp);

  //total counter upd
  long total = 0;
  //FM24C_read(TotalPagesFramAddress, &total, sizeof(total));
  total = FramReadLong(TotalPagesFramAddress);
  total++;
  //FM24C_write(TotalPagesFramAddress, &total, sizeof(total));
  FramWriteLong(TotalPagesFramAddress, total);
  perSessionPages++;
}



void fastDisplayBuffer() {
  EPD_5IN83_V2_Power(true);
  EPD_5IN83_V2_TurnOnDisplay();
}
void displayBuffer() {
  EPD_5IN83_V2_Display();
  //EPD_5IN83_Sleep();
}

// value from 0 to 7, higher values more brighter
void setSSD1306VcomDeselect(uint8_t v) {
  u8x8_cad_StartTransfer(u8g2.getU8x8());
  u8x8_cad_SendCmd(u8g2.getU8x8(), 0x0db);
  u8x8_cad_SendArg(u8g2.getU8x8(), v << 4);
  u8x8_cad_EndTransfer(u8g2.getU8x8());
}

// p1: 1..15, higher values, more darker, however almost no difference with 3 or more
// p2: 1..15, higher values, more brighter
void setSSD1306PreChargePeriod(uint8_t p1, uint8_t p2) {
  u8x8_cad_StartTransfer(u8g2.getU8x8());
  u8x8_cad_SendCmd(u8g2.getU8x8(), 0x0d9);
  u8x8_cad_SendArg(u8g2.getU8x8(), (p2 << 4) | p1);
  u8x8_cad_EndTransfer(u8g2.getU8x8());
}

void clearOled() {
  u8g2.clearBuffer();  // clear the internal memory
  u8g2.sendBuffer();   // transfer internal memory to the display
}

void OledSetContrast() {
  if (OledContrast < 4) {
    setSSD1306PreChargePeriod(15, 1);
    setSSD1306VcomDeselect(0);
    u8g2.setContrast(0);
  } else {
    setSSD1306PreChargePeriod(1, 15);
    setSSD1306VcomDeselect(7);
    u8g2.setContrast(OledContrast * 4);
  }
}
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
void loop() {
  //return;



  interrupts();  //re-enables interrupts

#ifdef USE_DEBUG

  //if (hasFramBookmark())
  //loadFramBookmark();

#endif

  set_sleep_mode(SLEEP_MODE_PWR_DOWN);  // PowerDown - самый экономный режим
  sleep_mode();                         // Переводим МК в сон

  readGyroData(gyroCount);
  getGres();
  // Calculate the gyro value into actual degrees per second
  gyrox = (float)gyroCount[0] * gRes;  // get actual gyro value, this depends on scale being set
  gyroy = (float)gyroCount[1] * gRes;
  gyroz = (float)gyroCount[2] * gRes;
  auto gyroApply = gyrox;  //gyroy for old panel driver2
  auto gyroMenu = gyroz;
  int biggestIdx = -1;

  float biggestVal = -999;
  float biggestAbsVal = -999;

  bool mask[3] = { true, true, true };
  if (menuMode != menuModeEnum::files) {
    mask[1] = false;
  }

  for (int i = 0; i < 3; i++) {
    if (!mask[i])
      continue;
    auto val = (float)gyroCount[i] * gRes;
    if (abs(val) > biggestAbsVal || biggestIdx == -1) {
      biggestVal = val;
      biggestAbsVal = abs(val);
      biggestIdx = i;
    }
  }

  if (trigger) {

    if (biggestAbsVal > threshold) {

      bool dir = biggestVal > 0 ? false : true;
      switch (biggestIdx) {
        case 0:
          {
            if (applyRevert)
              dir = !dir;

            applyButton(dir ? 1 : -1);
            trigger = false;
          }
          break;
        case 1:
          {
            auxMenuButton(dir ? 1 : -1);
            trigger = false;
          }
          break;
        case 2:
          {
            menuButton(dir ? 1 : -1);
            trigger = false;
          }
          break;
      }
    }


    if (!trigger) {

      triggerCounter++;
      if (triggerCounter == TriggerCheckDivisor) {  //check voltage each TriggerCheckDivisor times
        triggerCounter = 0;
        //ina219.powerUp();

        MeasureLoadVoltage();
        if (NeedShutdown()) {
          //todo: disable ports, oled, mpu, epd
          clearOled();
          DisableMPU();

          Shutdown();
        }
        UpdateTriggerCheckDivisor();
      }
      delay(triggerDelay);
    }
  }


  //  Serial.print(taps);
  //  Serial.print("         ,");  Serial.print(gyrox);
  // Serial.print(",");  Serial.print(gyroy);
  // Serial.print(",");  Serial.print(gyroz);  Serial.print(",");
  readdata = readByte(MPU6050_ADDRESS, 0x3A);
  //Serial.print(readdata);
  //Serial.println();



  noInterrupts();  // to disable interrupts
}

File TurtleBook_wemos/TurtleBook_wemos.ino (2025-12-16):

/*
   Print size, modify date/time, and name for all files in root.
*/
#include "SdFat.h"
#include <SPI.h>
int x;
#include <ESP8266WiFi.h>
#include <WiFiClient.h>
#include <ESP8266WebServer.h>
#include <ESP8266mDNS.h>


#ifndef APSSID
#define APSSID "ESPap"
#define APPSK "thereisnospoon"
#endif
/* Set these to your desired credentials. */
const char* ssid = APSSID;
const char* password = APPSK;

ESP8266WebServer server(80);

const bool DecryptZCB = false;

//File root;
/**
   data
**/
#define UBYTE uint8_t
#define UWORD uint16_t
#define UDOUBLE uint32_t

/**
   SPI RAM
**/
#define EPD_CS D1
#define EPD_RST D1
//#define SD_CS D4
#define SPIRAM_CS D3


#define SPIRAM_CS_0 digitalWrite(SPIRAM_CS, LOW)
#define SPIRAM_CS_1 digitalWrite(SPIRAM_CS, HIGH)

/**
   SD Card
**/

#define SD_CS_0 digitalWrite(SD_CS, LOW)
#define SD_CS_1 digitalWrite(SD_CS, HIGH)
/**
   e-Paper GPIO
**/

#define EPD_CS_0 digitalWrite(EPD_CS, LOW)
#define EPD_CS_1 digitalWrite(EPD_CS, HIGH)

//#define EPD_DC 9



#define EPD_RST_0 digitalWrite(EPD_RST, LOW)
#define EPD_RST_1 digitalWrite(EPD_RST, HIGH)




#define EPD_RST_PIN EPD_RST
#define EPD_DC_PIN EPD_DC
#define EPD_CS_PIN EPD_CS
#define EPD_BUSY_PIN EPD_BUSY

/**
   GPIO read and write
**/
#define DEV_Digital_Write(_pin, _value) digitalWrite(_pin, _value == 0 ? LOW : HIGH)
#define DEV_Digital_Read(_pin) digitalRead(_pin)

/**
   SPI
**/

// SD_FAT_TYPE = 0 for SdFat/File as defined in SdFatConfig.h,
// 1 for FAT16/FAT32, 2 for exFAT, 3 for FAT16/FAT32 and exFAT.
#define SD_FAT_TYPE 3
/*
  Change the value of SD_CS_PIN if you are using SPI and
  your hardware does not use the default value, SS.
  Common values are:
  Arduino Ethernet shield: pin 4
  Sparkfun SD shield: pin 8
  Adafruit SD shields and modules: pin 10
*/

// SDCARD_SS_PIN is defined for the built-in SD on some boards.
#ifndef SDCARD_SS_PIN
const uint8_t SD_CS_PIN = D2;
#else   // SDCARD_SS_PIN
// Assume built-in SD is used.
const uint8_t SD_CS_PIN = SDCARD_SS_PIN;
#endif  // SDCARD_SS_PIN

// Try max SPI clock for an SD. Reduce SPI_CLOCK if errors occur.
#define SPI_CLOCK SD_SCK_MHZ(50)

// Try to select the best SD card configuration.
//#if HAS_SDIO_CLASS
//#define SD_CONFIG SdioConfig(FIFO_SDIO)
//#elif  ENABLE_DEDICATED_SPI
//#define SD_CONFIG SdSpiConfig(SD_CS_PIN, DEDICATED_SPI, SPI_CLOCK)
//#else  // HAS_SDIO_CLASS
//#define SD_CONFIG SdSpiConfig(SD_CS_PIN, SHARED_SPI, SPI_CLOCK)
#define SD_CONFIG SdSpiConfig(SD_CS_PIN, DEDICATED_SPI, SPI_CLOCK)
//#endif  // HAS_SDIO_CLASS

UBYTE my_DEV_Module_Init(void) {
  //return 0;
  //set pin
  //pinMode(SPIRAM_CS, OUTPUT);
  //pinMode(SD_CS, OUTPUT);

  //pinMode(EPD_CS, OUTPUT);
  //pinMode(EPD_DC, OUTPUT);
  pinMode(EPD_RST, OUTPUT);

  EPD_RST_1;

  //EPD_CS_1;
  // SD_CS_1;
  //SPIRAM_CS_1;

  //set Serial
  //Serial.begin(115200);

  //set OLED SPI
  // SPI.beginTransaction(SPISettings(2000000, MSBFIRST, SPI_MODE0));
  /*   SPI.setDataMode(SPI_MODE0);
    SPI.setBitOrder(MSBFIRST);
    SPI.setClockDivider(SPI_CLOCK_DIV4);
    SPI.begin();
  */
  return 0;
  DEV_Digital_Write(EPD_RST_PIN, 1);
  delay(200);
  DEV_Digital_Write(EPD_RST_PIN, 0);
  delay(10);
  DEV_Digital_Write(EPD_RST_PIN, 1);
  delay(200);
  return 0;
}
#if SD_FAT_TYPE == 0
SdFat sd;
File dir;
File file;
#elif SD_FAT_TYPE == 1
SdFat32 sd;
File32 dir;
File32 file;
#elif SD_FAT_TYPE == 2
SdExFat sd;
ExFile dir;
ExFile file;
#elif SD_FAT_TYPE == 3
SdFs sd;
FsFile dir;
FsFile file;
FsFile sfile;
#else  // SD_FAT_TYPE
#error invalid SD_FAT_TYPE
#endif  // SD_FAT_TYPE
//------------------------------------------------------------------------------
// Store error strings in flash to save RAM.
#define error(s) sd.errorHalt(&Serial, F(s))
//------------------------------------------------------------------------------
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

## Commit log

2023-08-22 +ina219, +bmp mode, +hw i2c
2025-02-25 pcb soldering map
2025-02-25 +sample book
2025-03-20 led menu upd
2025-06-12 -old charger
2025-06-26 per page voltage drop statistic
2025-07-02 +panel driver pcb v4.0
2025-08-09 pcb bug fix
2025-10-08 +pcb version 5
2025-12-16 +cut/paste, web download upd
2026-02-02 case upd
    [bare_spacer_11mm.stp, bare_spacer_15mm.stp, bare_spacer_9mm.stp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]
2026-02-03 case 13mm upd
    [sider_stub_13mm.stp, stub3_shrinked_13mm.stp, stub3_shrinked_3.stp]
2026-03-08 pcb v6
